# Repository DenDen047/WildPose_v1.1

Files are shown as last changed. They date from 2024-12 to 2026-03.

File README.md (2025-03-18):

<p align="center">
  <h1 align="center">WildPose v1.1</h1>
  <p align="center">
    <a href="https://denden047.github.io/index_en.html">Naoya Muramatsu</a>
    ·
    <a href="https://www.linkedin.com/in/sangyun-shin-profile/?originalSubdomain=uk">Sangyun Shin</a>
    ·
    <a href="https://uk.linkedin.com/in/qianyi-deng">Qianyi Deng</a>
    ·
    <a href="https://www.cs.ox.ac.uk/people/andrew.markham/">Andrew Markham</a>
    ·
    <a href="https://scholar.google.com/citations?user=RxMigV4AAAAJ&hl=en">Amir Patel</a>
  </p>
  <h4 align="center">
    📚 <a href="https://www.biorxiv.org/content/10.1101/2024.02.05.578861v3">Paper</a> |
    🦒 <a href="https://denden047.github.io/wildpose">Project Page</a> |
    📂 <a href="https://u.pcloud.link/publink/show?code=kZdoxE0Z9rRj956ptaH6h0Btymik4X0jtGm7">Data</a>
  </h3>
</p>

<p align="center">

</p>
<div align=center>
This is the official implementation of our paper <a href="https://www.biorxiv.org/content/10.1101/2024.02.05.578861v4"><b>WildPose: A Long-Range 3D Wildlife Motion Capture System</b></a>.
</div>

## Citation

```bibtex
@article{10.1242/jeb.249987,
    author = {Muramatsu, Naoya and Shin, Sangyun and Deng, Qianyi and Markham, Andrew and Patel, Amir},
    title = {WildPose: a long-range 3D wildlife motion capture system},
    journal = {Journal of Experimental Biology},
    volume = {228},
    number = {5},
    pages = {JEB249987},
    year = {2025},
    month = {03},
    issn = {0022-0949},
    doi = {10.1242/jeb.249987},
    url = {https://doi.org/10.1242/jeb.249987},
    eprint = {https://journals.biologists.com/jeb/article-pdf/228/5/JEB249987/3637925/jeb249987.pdf},
}
```

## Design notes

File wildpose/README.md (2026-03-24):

# WildPose v1.1

## Hardware

### XIMEA -- MQ022CG-CM

Slide86

## Prerequisite

- JetPack v5
- ROS2 Foxy

## Setup

### Jetson AGX Xavier Developer Kit

#### JetPack

We used a [Jetson AGX Xavier Developer Kit](https://developer.nvidia.com/embedded/jetson-agx-xavier-developer-kit).
To set up the Jetson AGX Xavier Developer Kit, we need a host computer installed Ubuntu 20.04.

1. Download and install [NVIDIA SDK Manager](https://developer.nvidia.com/nvidia-sdk-manager) onto the host computer.
2. Connect the host computer and Jetson AGX Xavier Developer Kit (see this [video](https://www.youtube.com/watch?v=-nX8eD7FusQ)).
3. Run NVIDIA SDK Manager and follow the instruction.

Unleash the limitation of CPU ([the reference](https://forums.developer.nvidia.com/t/cpus-usage-problem-solved/65993/3)).
```bash
$ sudo nvpmodel -m 0
$ sudo /usr/bin/jetson_clocks --fan
```

#### General Settings

- Settings > Power > Blank Screen > `Never`

#### Network Configuration

On the Jetson, you can use `nmcli` command to change the network settings.

Set the static IP on the UCT network ([reference](https://f1tenth.readthedocs.io/en/stable/getting_started/software_setup/optional_software_nx.html)).
```bash
$ nmcli c show
NAME                UUID                                  TYPE      DEVICE
Wired connection 1  b72f3d20-4de2-3d44-9c45-9689d79f22e4  ethernet  eth0
docker0             bcb6f95d-5cf5-483d-ac09-c312a4da8c0b  bridge    docker0
$ sudo nmcli c modify "Wired connection 1" ipv4.address [NEW_ADDRESS]/27
```

#### SSH

***HOST COMPUTER***

For the ssh login from your computer, you should make a pair of ssh key on the host computer.
```bash
$ ssh-keygen -t rsa
```

Then, copy the public key into the Jetson.
```bash
$ ssh-copy-id -i ~/.ssh/wildpose_jetsonagx.pub [user]@[ip address]
```

Add the jetson IP address information in `~/.ssh/config`:
```
Host [ip address]
    HostName [ip address]
    User naoya
    IdentityFile ~/.ssh/wildpose_jetsonagx
    UseKeychain yes
    AddKeysToAgent yes
```

#### dotfiles

Set the dotfiles you wanna use (e.g., [Naoya's dotfiles](https://github.com/DenDen047/dotfiles)).

#### ROS2 Foxy

Let's install [ROS2 Foxy](https://docs.ros.org/en/foxy/index.html) following with [the official guide](https://docs.ros.org/en/foxy/Installation/Ubuntu-Install-Debians.html).
See `setup_scripts/ros2_foxy.sh`.

```bash
$ cd setup_scripts
$ ./ros2_foxy.sh
```

#### The Official Ximea Camera Driver

This is [the original GitHub repository](https://github.com/wavelab/ximea_ros_cam) and [the Guide for Jetson](https://www.ximea.com/support/wiki/apis/Linux_TX1_and_TX2_Support#Installing-XIMEA-API-package).

```bash
$ cd setup_scripts/
$ chmod +x ./xiapi.sh
$ ./xiapi.sh
# reopen the shell
```

##### Setup the USB FS Memory Max Allocation to Infinite

This is done to make sure that the USB FS buffering size is sufficient for high bandwidth streams through USB 3.0

*Set this with every new shell*:
Put `echo 0 > /sys/module/usbcore/parameters/usbfs_memory_mb` into `/etc/rc.local`

Or

*Apply to current shell*:
`echo "0" | sudo tee /sys/module/usbcore/parameters/usbfs_memory_mb`

#### ROS2 Packages

To show the ximea camera image data, you are recommended to install [image_view](https://index.ros.org/p/image_view/).

```bash
$ sudo apt install -y ros-foxy-image-view \
    ros-foxy-rqt-image-view \
    ros-foxy-rqt-reconfigure \
    ros-foxy-image-transport-plugins \
    ros-foxy-camera-info-manager
```

#### XIMEA Camera Driver for ROS2

```bash
$ mkdir ~/ros2_ws
$ cd ~/ros2_ws
$ git clone git@github.com:African-Robotics-Unit/ximea_ros2_cam.git
$ cd ~/ros2_ws/ximea_ros2_cam/
$ git fetch
$ git checkout -b develop
$ sudo apt install -y ros-foxy-camera-info-manager
$ colcon build
$ colcon build --packages-select cam_bringup --symlink-install

# Test the camera driver
$ ros2 launch cam_bringup cam_test.launch.py
```

Then, add `source ~/ros2_ws/ximea_ros2_cam/install/setup.bash` into `~/.bashrc`.

To avoid the [error 45](https://github.com/Fu-physics/Ximea/blob/master/xiPython/v3/ximea/xidefs.py#L49), you have to run the following command.

```bash
$ sudo tee /sys/module/usbcore/parameters/usbfs_memory_mb >/dev/null <<<0
```

#### Livox-SDK

This is [the original GitHub repository](https://github.com/Livox-SDK/Livox-SDK).

```bash
$ sudo apt install -y cmake gcc-aarch64-linux-gnu g++-aarch64-linux-gnu
$ cd ~/Documents
$ git clone https://github.com/Livox-SDK/Livox-SDK.git
$ cd Livox-SDK
```

Edit `Livox-SDK/sdk_core/CMakeLists.txt` by adding `-fPIC`.
Ref: https://github.com/Livox-SDK/livox_ros2_driver/issues/9#issuecomment-1048578018

```bash
$ cd build && cmake .. -DCMAKE_SYSTEM_NAME=Linux -DCMAKE_C_COMPILER=aarch64-linux-gnu-gcc -DCMAKE_CXX_COMPILER=aarch64-linux-gnu-g++
$ make
$ sudo make install
$ source /opt/ros/foxy/setup.bash
```

Set the network configuration:
- IP address: `192.168.1.2`
- Netmask: `255.255.255.0`
- Gatway: `192.168.1.1`

#### Livox ROS2 Driver

This is [the original GitHub repository](https://github.com/Livox-SDK/livox_ros2_driver).

```bash
$ sudo apt install -y ros-foxy-rviz2
$ cd ~/ros2_ws
$ git clone https://github.com/DenDen047/livox_ros2_driver.git livox_ros2_driver/src
$ cd livox_ros2_driver
$ colcon build
$ source ~/ros2_ws/livox_ros2_driver/install/setup.bash
```

Add `source ~/ros2_ws/livox_ros2_driver/install/setup.bash` into `~/.bashrc`.
Don't forget to change **the config file**.

#### rmw_ecal

Update the ROS middleware for fast recording ros bag files.

Install [eCAL](https://github.com/eclipse-ecal/ecal).
```bash
$ sudo add-apt-repository ppa:ecal/ecal-latest
$ sudo apt-get update
$ sudo apt-get install -y ecal
```

Setup [rosidl_typesupport_protobuf](https://github.com/eclipse-ecal/rosidl_typesupport_protobuf).
```bash
$ sudo apt-get install -y libprotobuf-dev protobuf-compiler
$ cd ~/ros2_ws
$ git clone https://github.com/eclipse-ecal/rosidl_typesupport_protobuf.git
$ cd ~/ros2_ws/rosidl_typesupport_protobuf
$ colcon build
$ vim ~/.bashrc   # add "source ~/ros2_ws/rosidl_typesupport_protobuf/install/setup.bash"
$ source ~/.bashrc
```

Clone latest release of this repository into your ROS2 workspace and build it.
```bash
$ cd ~/ros2_ws
$ git clone https://github.com/eclipse-ecal/rmw_ecal.git
$ cd ~/ros2_ws/rmw_ecal
$ colcon build --packages-skip rmw_ecal_proto_cpp
$ vim ~/.bashrc   # add "source ~/ros2_ws/rmw_ecal/install/setup.bash"
$ source ~/.bashrc
```

Add the following line into your `.bashrc`.
```bash
export RMW_IMPLEMENTATION=rmw_ecal_dynamic_cpp
```

Install Python eCAL API.
```bash
$ sudo apt install -y python3 python3-pip
$ sudo apt install -y python3-ecal5
```

#### jtop

To check the Jetson status, [`jtop`](https://github.com/rbonghi/jetson_stats) should be installed.
```bash
$ sudo -H pip install -U jetson-stats
$ sudo reboot
```

#### Wi-Fi

You should get a connection listing similar to something like this:

```bash
$ nmcli d
DEVICE         TYPE      STATE         CONNECTION
wlan0          wifi      connected     AirPort41594
docker0        bridge    connected     docker0
p2p-dev-wlan0  wifi-p2p  disconnected  --
eth0           ethernet  unavailable   --
...
```

Next we will make sure that the WiFi module is turned on by typing the following command:

```bash
$ nmcli r wifi on
```

Now we can scan and list off all visible WiFi networks available to us by typing the following command:

```bash
$ nmcli d wifi list
IN-USE  BSSID              SSID          MODE   CHAN  RATE        SIGNAL  BARS  SECURITY
*       34:76:C5:37:A2:7A  AirPort41594  Infra  6     130 Mbit/s  87      ▂▄▆█  WPA1 WPA2
...
```

To connect to a given network make sure you have its SSID and password ready. Both are case sensitive! Type the following command with `[SSID]` being your SSID and `[PASSWORD]` being the password for that network:

```bash
$ nmcli d wifi connect [SSID] password [PASSWORD]
```

If all goes according to plan, you should get a connection confirmation!

#### CAN bus setting

```bash
$ sudo apt install -y busybox
```

Add the following code into your `/etc/rc.local`:
```bash
sh /home/naoya/WildPose_v1.1/wildpose/src/dji_rs3_pkg/enable_CAN.sh &
```

Check the status of `can0`:
```bash
$ ip -s -d -h link show can0
```

Check the CAN connection.
```bash
# AA:1A:00:03:00:00:00:00  22:11:A2:42:0E:00:20:00  30 00 40 00 01 14 7B 40  97 BE
$ cansend can0 223#AA1A000300000000 && \
    cansend can0 223#2211A2420E002000 && \
    cansend can0 223#3000400001147B40 && \
    cansend can0 223#97BE
```

References:
- [Enabling CAN on Nvidia Jetson Xavier Developer Kit](https://medium.com/@ramin.nabati/enabling-can-on-nvidia-jetson-xavier-developer-kit-aaaa3c4d99c9)
- [hmxf/can_xavier -- GitHub](https://github.com/hmxf/can_xavier)
- [Controller Area Network (CAN) -- nVIDIA](https://docs.nvidia.com/jetson/archives/r34.1/DeveloperGuide/text/HR/ControllerAreaNetworkCan.html)

#### Remote Desktop

```bash
$ sudo apt install -y xrdp
$ cd
$ echo "xfce4-session" | tee .xsession
$ sudo reboot
```

#### Logitech Wireless Gamepad F710

Mode `X`.

```bash
$ usb-devices
...
T:  Bus=01 Lev=02 Prnt=03 Port=02 Cnt=01 Dev#= 10 Spd=12  MxCh= 0
D:  Ver= 2.00 Cls=ff(vend.) Sub=ff Prot=ff MxPS= 8 #Cfgs=  1
P:  Vendor=046d ProdID=c21f Rev=03.05
S:  Manufacturer=Logitech
S:  Product=Wireless Gamepad F710
S:  SerialNumber=3DA39E79
C:  #Ifs= 1 Cfg#= 1 Atr=80 MxPwr=98mA
I:  If#=0x0 Alt= 0 #EPs= 2 Cls=ff(vend.) Sub=5d Prot=01 Driver=xpad
...
```

Check the connection between Jetson and F710.

```bash
$ sudo apt-get install -y jstest-gtk
$ jstest /dev/input/js0
```

Install `joy_linux` package.

```bash
$ sudo apt install -y ros-foxy-joy-linux
$ ros2 run joy_linux joy_linux_node --ros-args -p dev_name:="Wireless Gamepad F710"
```

#### Motor Controller with Teensy 4.0

Install the preprequirements.

```bash
$ sudo apt-get install -y python3-serial
```

TTY setting.

```bash
$ systemctl stop nvgetty
$ systemctl disable nvgetty
$ udevadm trigger
```

Add an user group, `dialout`, to use tty ports without sudo.

```bash
$ sudo usermod -aG dialout ${USER}
```

Then, you should reboot the jetson.

References
- [Jetson Nano – UART](https://jetsonhacks.com/2019/10/10/jetson-nano-uart/)
- [Permission denied when try connect on /dev/ttyTHS1](https://forums.developer.nvidia.com/t/permission-denied-when-try-connect-on-dev-ttyths1/210479/10)

#### Jetson AGX Orin for Teensy 4.0

This is the setup on Jetson AGX Orin for Teensy 4.0.

```bash
$ sudo usermod -a -G tty naoya
```

### Host Computer

To develop ROS2 programs on your host/local computer, VS Code ROS Extension was used.
Please refer to see the following video:

<iframe width="560" height="315" src="https://www.youtube.com/embed/teA20AjBlG8" title="YouTube video player" frameborder="0" allow="accelerometer; autoplay; clipboard-write; encrypted-media; gyroscope; picture-in-picture" allowfullscreen></iframe>

#### VSCode

Recommend Extensions:
- [C/C++ Extension Pack](https://marketplace.visualstudio.com/items?itemName=ms-vscode.cpptools-extension-pack)
- [CMake](https://marketplace.visualstudio.com/items?itemName=twxs.cmake)
- [Python](https://marketplace.visualstudio.com/items?itemName=ms-python.python)
- [ROS2](https://marketplace.visualstudio.com/items?itemName=nonanonno.vscode-ros2)

## Build

```bash
$ cd ~/WildPose_v1.1/wildpose
$ colcon build --symlink-install
```

## Usage

Run WildPose with the following commmand, and the data will be recorded in a rosbag file in `rosbags/`.

```bash
$ sudo ip link set down can0 && sudo ip link set up can0
$ ros2 launch wildpose_bringup wildpose_launch.py
```

After that, you can open eCAL Recorder.
Note that `cam_context` file is generated when the system starts up, so its timestamp will always be earlier than that of the eCAL file.

```bash
$ ecal_rec_gui --config ~/WildPose_v1.1/wildpose/src/wildpose_bringup/config/config.ecalrec --activate
```

## Generate Video

Install requirements:

```bash
$ sudo apt install -y ffmpeg
$ sudo apt install -y python3-roslib python3-rospy python3-sensor-msgs python3-opencv
$ pip3 install tqdm ffmpeg-python
```

Convert a rosbag file into a video file:

```bash
$ cd src/
$ ./rosbag2video.py --input_db ~/WildPose_v1.1/wildpose/rosbags/20221002_192302/20221002_192302_0.db3
```

## Replay

```bash
$ ros2 run image_view image_view --ros-args --remap /image:=/image_raw
```

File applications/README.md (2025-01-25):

# WildPose Applications

This repository contains the code for the figures and tables in the WildPose paper.

## Setting up the environment

```bash
conda env create -f environment.yml
conda activate wildpose
```

## File Organization for a scene data

The data is organized as follows:

```
data/
├── manual_calibration.json
├── sync_rgb/
│   ├── 000001.jpeg
│   ├── 000002.jpeg
│   ├── 000003.jpeg
│   ├── ...
├── lidar/
│   ├── 000001.pcd
│   ├── 000002.pcd
│   ├── 000003.pcd
│   ├── ...
├── masks/
    ├── 000001.png
    ├── 000002.png
    ├── 000003.png
    ├── ...
```

where `sync_rgb` is the synchronized RGB images, `lidar` is the LiDAR point clouds, and `masks` is the masks of the animals.

## Making the figures and tables in the WildPose paper

### Introduction section

Fig. 1D.
```bash
python make_depth_image.py
```

### Calibration Validation

For the calibration validation figures (Fig. 2A), run:
```bash
python plot_calib_validation.py             # Fig. S1
python plot_calib_validation_by_angles.py   # Fig. 2A
```

### Object Tracking Precision

Analyze the validation results of the object tracking precision.
```bash
# First, run the validation:
python validate_trajectory.py \
    --mode position_2d \
    --data_dir /path/to/data
./batch_validate_trajectory.sh

# Then generate figures:
python plot_trajectory_validation_by_circles.py # Fig. 2D
python plot_motion_validation.py                # Fig. 2E
python create_synthetic_figure.py               # Fig. S2
```

### Animal Morphology & Locomotion

Get the morphometrics data (Table 1).
```bash
python measure_morphometrics.py
```

Fig. 3A&B.
```bash
python plot_keypoints.py
```

- `single_frame` mode (Fig. 3A)
- `left_{front|hind}_leg` mode (Fig. 3B)

Fig. S3.
```bash
python plot_coloured_pcd.py
```

### Tracking Individual Animals in 3D

```bash
python plot_3d_trajectory.py    # Supports multiple modes:
# --mode position_3d            # Fig. S4A
# --mode position_without_y     # Fig. 3C
# --mode velocity               # Fig. S4B-D
# --mode neighbor_density       # Fig. 3D
# --mode neighbor_density_animation # Movie 1
```

### Fine Scale Deformation Monitoring

Prerequisites:
1. Generate bounding boxes for target animals
2. Predict individual masks using Segment Anything (`segment_anything.py`)
3. Estimate body size transitions (`body_size_estimator.py`)

```bash
python plot_breathing.py    # Supports modes:
# --mode filtered   # Fig. 4A
# --mode fft        # Fig. 4B
# --mode imu        # Fig. 4C and 4D
```

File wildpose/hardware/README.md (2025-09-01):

# Wildpose_CAD_Model
This is the CAD Folder including all the files for the Wildpose Camera Rig.

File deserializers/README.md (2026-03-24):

logo

# eCAL Deserializers

## Description

This repo contains deserializers for [eCAL](https://github.com/eclipse-ecal/rmw_ecal) measurements of four ROS2 messages used in our [M2S2](m2s2_ws) drivers.

The deserializers extract the raw data stored in the .hdf5 files and converts it into desirable data according to their message definitons.

Messages:

1. standard [ROS2](https://docs.ros.org/en/foxy/index.html) sensor_msgs/msg/Image
2. custom M2S2 flir_boson_interfaces/msg/ThermalRaw
3. custom M2S2 bme280_interfaces/msg/EnviroData
4. custom M2S2 radar_interfaces/msg/Frame

## Install

[eCAL](https://github.com/eclipse-ecal/ecal)

```bash
sudo add-apt-repository ppa:ecal/ecal-5.13
sudo apt update
sudo apt install -y ecal
```

[ROS2 Humble](https://docs.ros.org/en/humble/Installation/Ubuntu-Install-Debs.html)

```bash
sudo apt install software-properties-common
sudo add-apt-repository universe

sudo apt update && sudo apt install curl -y
export ROS_APT_SOURCE_VERSION=$(curl -s https://api.github.com/repos/ros-infrastructure/ros-apt-source/releases/latest | grep -F "tag_name" | awk -F\" '{print $4}')
curl -L -o /tmp/ros2-apt-source.deb "https://github.com/ros-infrastructure/ros-apt-source/releases/download/${ROS_APT_SOURCE_VERSION}/ros2-apt-source_${ROS_APT_SOURCE_VERSION}.$(. /etc/os-release && echo ${UBUNTU_CODENAME:-${VERSION_CODENAME}})_all.deb"
sudo dpkg -i /tmp/ros2-apt-source.deb

sudo apt update && sudo apt upgrade -y
sudo apt install -y ros-humble-desktop ros-dev-tools
mkdir -p ~/ros2_ws/src

# add the below command to .bashrc
source /opt/ros/humble/setup.bash

rosdep init
rosdep update
```

[rmw_ecal](https://github.com/eclipse-ecal/rmw_ecal)

```bash
cd ~/ros2_ws/src
sudo apt install -y \
    ros-humble-osrf-testing-tools-cpp \
    ros-humble-test-msgs \
    ros-humble-image-view
git clone https://github.com/eclipse-ecal/rosidl_typesupport_protobuf.git
git clone https://github.com/eclipse-ecal/rmw_ecal
sudo apt install -y libprotobuf-dev protobuf-compiler
colcon build --symlink-install --cmake-args -DBUILD_TESTING=OFF

# add the below commands to ~/.bashrc
export RMW_IMPLEMENTATION=rmw_ecal_dynamic_cpp
source ~/ros2_ws/src/install/setup.bash
```

## Trim eCAL measurement file

Usually, eCAL data is super large.
So, we recommend to [trim the eCAL file](https://eclipse-ecal.github.io/ecal/stable/applications/meas_cutter/meas_cutter.html) before deserialisation.

First, you need to check the timestamp on eCAL player and ROS2 `image_view`:

```bash
ros2 run image_view image_view --ros-args --remap /image:=/image_raw
```

Then edit the `deserializers/ecal_cutter_config.yml` and run eCAL cutter:

```bash
cd deserializers
vim ecal_cutter_config.yml
./ecal_cutter.sh
```

Or you can cut scenes at once:

```bash
cd deserializers
uv run python batch_ecal_cutter.py
```

Note: the input and output arguments of `ecal_meas_cutter` should be folder paths.

## Usage

First of all, you have build the whole folder.

```bash
$ cmake .
```

Or run at once:

```bash
$ cd deserializers
$ sudo apt update && sudo apt install -y ffmpeg
$ uv run python deserializer.py --meas_dir [meas_dir_path] --skip_raw
```

Or you can batch-deserialize:

```bash
$ cd deserializers
$ LOGURU_LEVEL=INFO uv run python batch_deserializer.py --parent_dir [parent_dir_of_meas_dirs]
```

## YouTube Batch Upload

Upload videos to YouTube with pCloud shared links in the description.

### Upload new videos

```bash
uv run python batch_uploader.py --parent_dir /mnt/vault/WildPose_dataset
```

### Dry run (preview without uploading)

```bash
uv run python batch_uploader.py --parent_dir /mnt/vault/WildPose_dataset --dry_run
```

### Update descriptions of already-uploaded videos

Add pCloud shared links to existing YouTube videos:

```bash
uv run python batch_uploader.py --parent_dir /mnt/vault/WildPose_dataset --update_descriptions
```

Preview changes first:

```bash
uv run python batch_uploader.py --parent_dir /mnt/vault/WildPose_dataset --update_descriptions --dry_run
```

### Prerequisites

- YouTube OAuth2 token (see setup below)
- [rclone](https://rclone.org/) configured with `pCloud:` remote (for pCloud shared links)

### YouTube OAuth2 token setup

1. Create a project on [Google Cloud Console](https://console.cloud.google.com/) and enable YouTube Data API v3
2. Go to "APIs & Services > Credentials" and create an OAuth 2.0 Client ID (type: Desktop app)
3. Download the client secret JSON and place it at:
   ```
   .secrets/youtube_api_v3_client_secret.json
   ```
4. Run the authentication script (a browser window will open for Google account login):
   ```bash
   uv run python tools/test_youtube_auth.py
   ```
5. On success, the token is saved to `.secrets/youtube_token.json`

**Token renewal**: If you get an `invalid_grant` error, delete the token file and re-authenticate:

```bash
rm .secrets/youtube_token.json
uv run python tools/test_youtube_auth.py
```

### Ximea Camera Deserializer

This [deserializer](src/deserialize_ximea.cpp) converts a recorded ecal measurement of type [sensor_msgs/msg/Image](http://docs.ros.org/en/noetic/api/sensor_msgs/html/msg/Image.html) into RGB .jpeg images.

**NOTE:** Ximea API's demosaic color defect correction is not optimized for ARM processors, and so performance may degrade significantly. To avoid this, we captured raw 8-bits or 16-bits images (by setting the *format* parameter to **RAW8** or **RAW16** in the config file of the [M2S2 ROS2 driver](add link)) and we post-process later using the API's [offline processing](https://www.ximea.com/support/wiki/apis/XiAPI_Offline_Processing), by saving the camera context each time data is collected.

[xiAPI](https://www.ximea.com/support/wiki/apis/XIMEA_Linux_Software_Package)

```bash
# download package
wget  https://updates.ximea.com/public/ximea_linux_sp_beta.tgz
tar xzf ximea_linux_sp_beta.tgz
cd package

# install
sudo apt-get update
sudo apt-get install build-essential linux-headers-"$(uname -r)"
sudo apt-get install libtiff5
./install
```

build with:

```bash
$ cmake --build . --target ximea
```

run:

```bash
./ecal_sample_ximea 'meas_folder_path' 'channel_name' 'cam_context_path' 'out_path_rgb' 'out_path_raw' [image_format]
```

where:

- `meas_folder_path` is the path to the input eCAL measurement folder
- `channel_name` is the channel you wish to deserialize. (This is often `rt/image_raw`)
- `cam_context_path` is the path to where the camera context file is saved for a specific measurement, to perform post-processing of the raw ximea images
- `out_path_rgb` is the path to where you wish to store the post-processed RGB images
- `out_path_raw` is the path to where you wish to store the post-processed RAW images (set to `none` to skip raw image generation)
- `image_format` (optional) is the output image format for RGB images: `webp` (default, lossless) or `jpeg` (quality=95)

Examples:

```bash
# Generate both RGB and RAW images (default: WebP format)
./ecal_sample_ximea /path/to/meas rt/image_raw /path/to/cam_context.bin /path/to/rgb/ /path/to/raw/

# Generate only RGB images (skip RAW)
./ecal_sample_ximea /path/to/meas rt/image_raw /path/to/cam_context.bin /path/to/rgb/ none

# Generate RGB images in JPEG format (skip RAW)
./ecal_sample_ximea /path/to/meas rt/image_raw /path/to/cam_context.bin /path/to/rgb/ none jpeg
```

### Livox Deserializer

This [deserializer](src/deserialize_livox.cpp) converts a recorded ecal measurement of type [sensor_msgs/msg/PointCloud2](http://docs.ros.org/en/melodic/api/sensor_msgs/html/msg/PointCloud2.html) into a pcd file using the [Point Cloud Library](https://github.com/PointCloudLibrary/pcl).

dependencies:

```bash
$ sudo apt install -y libpcl-dev
$ sudo apt install -y python3-pcl pcl-tools
$ git clone git@github.com:PointCloudLibrary/pcl.git
$ cd pcl
$ mkdir build
$ cd build
$ cmake ..
$ make -j8
$ sudo make install
```

build with:

```bash
$ cmake --build . --target livox_imu lidar
```

run:

```bash
$ ./ecal_sample_lidar 'meas_folder_path' 'channel_name' 'out_path'
```

where:

- `meas_folder_path` is the path to the input eCAL measurement folder
- `channel_name` is the channel you wish to deserialize. (This is often `rt/livox/lidar`)
- `out_path` is the folder path to where you wish to store the pcd files

The IMU data structure:

```msg
std_msgs/Header header
    int32 sec
    int32 nanosec
    string frame_id

geometry_msgs/Quaternion orientation
    float64 x   # Default: 0
    float64 y   # Default: 0
    float64 z   # Default: 0
    float64 w   # Default: 1
float64[9] orientation_covariance   # Row major about x, y, z axes

geometry_msgs/Vector3 angular_velocity
    float64 x
    float64 y
    float64 z
float64[9] angular_velocity_covariance  # Row major about x, y, z axes

geometry_msgs/Vector3 linear_acceleration
    float64 x
    float64 y
    float64 z
float64[9] linear_acceleration_covariance   # Row major x, y z
```

### BME280 Deserializer

This [deserializer](src/deserialize_bme280.cpp) converts a recorded ecal measurement of type [bme280_interfaces/msg/EnviroData](m2s2_ws/src/bme280_ROS2_driver/bme280_interfaces/msg/EnviroData.msg) into a JSON file with the following fields for each measurement: frame_id, timestamp_secs, timestamp_nanosecs, temperature, pressure, humidity.

build with:

```bash
$ cmake --build . --target bme280
```

run:

```bash
./ecal_sample_bme280 'meas_path' 'channel_name' 'out_file_name'
```

where:

- `meas_path` is the path to the input eCAL measurement file
- `channel_name` is the channel you wish to deserialize. (This is often `rt/ros2_topic_name`)
- `out_file_name` is the name of the JSON file you wish to save the data to

### FLIR Boson Deserializer

This [deserializer](src/deserialize_flir_boson.cpp) converts a recorded ecal measurement of type [flir_boson_interfaces/msg/ThermalRaw](m2s2_ws/src/flir_boson_ROS2_driver/flir_boson_interfaces/msg/ThermalRaw.msg) into raw 16 bit .png images, as well as grayscale false-coloured .jpeg images.

build with:

```bash
$ cmake --build . --target boson
```

run:

```bash
./ecal_sample_boson 'meas_path' 'channel_name' 'out_path_raw' 'out_path_rgb'
```

where:

- `meas_path` is the path to the input eCAL measurement file
- `channel_name` is the channel you wish to deserialize. (This is often `rt/ros2_topic_name`)
- `out_path_raw` is the path to where you wish to store the 16 bit raw images
- `out_path_rgb` is the path to where you wish to store the false-coloured images

### Radar Deserializer

This [deserializer](src/deserialize_radar.cpp) converts a recorded ecal measurement of type [radar_interfaces/msg/Frame](m2s2_ws/src/radar_ROS2_driver/radar_interfaces/msg/Frame.msg) into a JSON file with the following fields for each radar frame: frame_id, timestamp_secs, timestamp_nanosecs, frame_size, frame_data.

build with:

```bash
$ cmake --build . --target radar
```

run:

```bash
./ecal_sample_radar 'meas_path' 'channel_name' 'out_file_name'
```

where:

- `meas_path` is the path to the input eCAL measurement file
- `channel_name` is the channel you wish to deserialize. (This is often `rt/ros2_topic_name`)
- `out_file_name` is the name of the JSON file you wish to save the data to

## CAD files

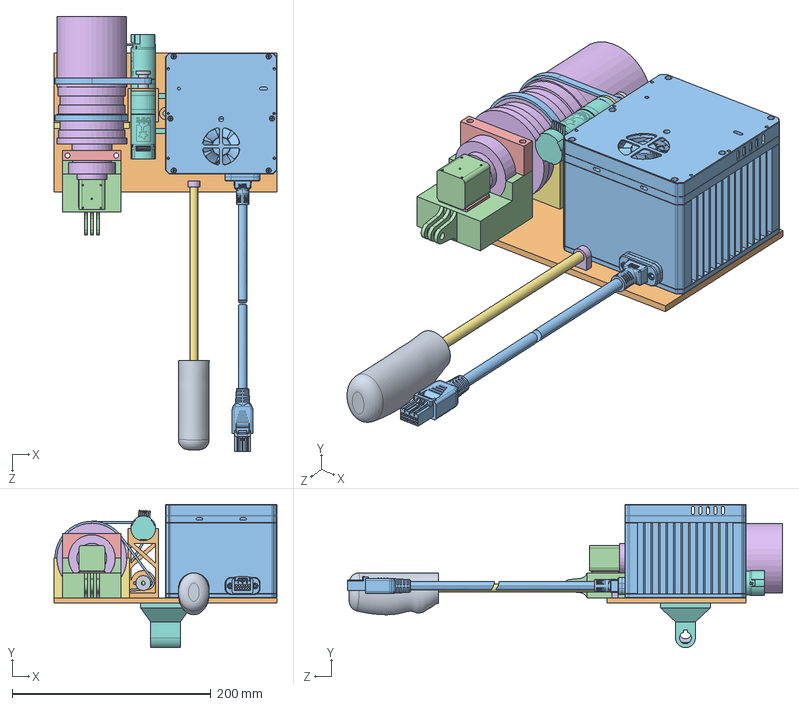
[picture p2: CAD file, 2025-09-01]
wildpose/hardware/CameraAssembly.SLDASM
224.0 x 144.2 x 437.2 mm
WLDPOSE009 Camera Plate
Tele-15_shell_FOV_3D.stp
Zimea Camera MQ022CG-CM
Camera Mount
Lens
Lens Support
25d-metal-gearmotor-75-99-encoder.step x 2
Belt Pulley 778-4828 x 2
Motor Mount
Motor Belt x 2
Ximea Holder
Ximea Holder 2
WLDPOSE010 Handle Connector
HandleRod
WLDPOSE008 Pitch Shaft Connector v2
Handle

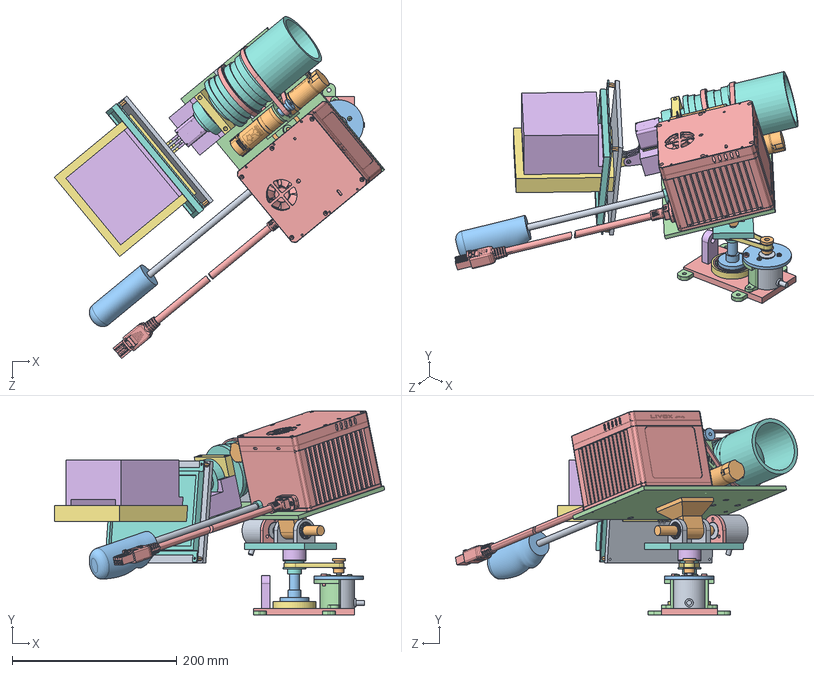
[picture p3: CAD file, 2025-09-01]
wildpose/hardware/Full Rig.SLDASM
401.7 x 247.6 x 415.7 mm
Optical Encoder x 2
18 T 2.032mm P , 6mm W Pulley
Encoder Coupler
DIN 7984 - M3 x 10 --- 8.5NPCS x 3
DIN 6912 - M4 x 12 --- 8.5NPCS x 2
Nvidea Xavier
Xavier Holder
QLED Screen
Screen Mount
RPi M3 Screw Connectors x 4
WLDPOSE009 Camera Plate
Tele-15_shell_FOV_3D.stp
Zimea Camera MQ022CG-CM
Camera Mount
Lens
Lens Support
25d-metal-gearmotor-75-99-encoder.step x 2
Belt Pulley 778-4828 x 2
Motor Mount
Motor Belt x 2
Ximea Holder
Ximea Holder 2
WLDPOSE010 Handle Connector
HandleRod
WLDPOSE008 Pitch Shaft Connector v2
Handle
WLDPOSE001 Base Wing Slots x 4
WLDPOSE002 Base Bilot
WLDPOSE003 Base Shaft Support Slot
WLDPOSE004 Bearing Holder
WLDPOSE005 Pitch Bilot
WLDPOSE006 Shaft Holder x 2
WLDPOSE007 Pitch Shaft
WLDPOSE011 Yaw shaft
Base Encoder Holder (Printed)
Pitch Encoder Holder (Printed)
Shaft Spacer (Printed)
Timing Belt 80 T 162.56mm x 6mm
36 T 2.032mm P, 6mm W Pulley
SKF_61801_16 x 24
SKF_61801_29 x 2
SKF_61801_31 x 2
SKF_61807_23 x 19
SKF_61807_43
SKF_61807_45
SKF_51200_3 x 9
SKF_51200_13
SKF_51200_15
SKF_51200_17

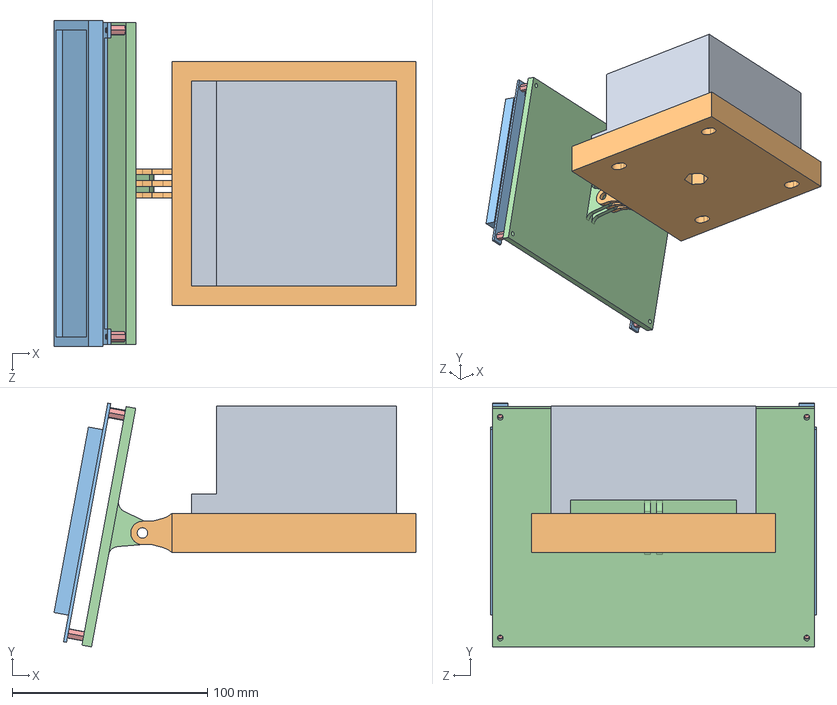
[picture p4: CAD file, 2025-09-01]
wildpose/hardware/Nvidea_Screen_Setup.SLDASM
185.3 x 124.8 x 166.9 mm
Nvidea Xavier
Xavier Holder
QLED Screen
Screen Mount
RPi M3 Screw Connectors x 4

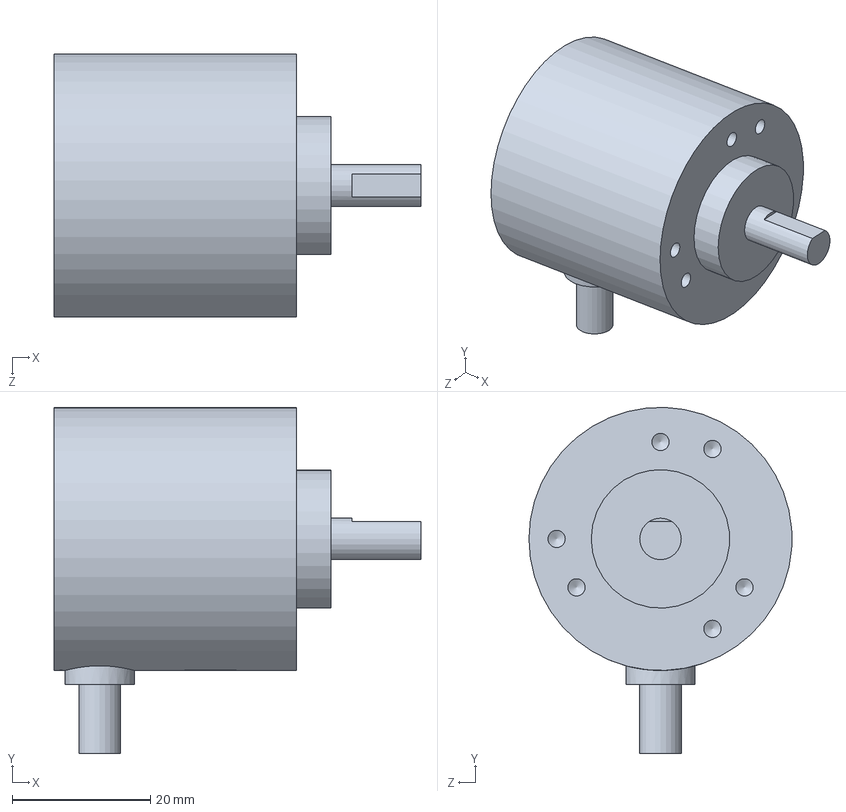
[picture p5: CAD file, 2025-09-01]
wildpose/hardware/Optical Encoder.SLDPRT
53.0 x 50.0 x 38.0 mm

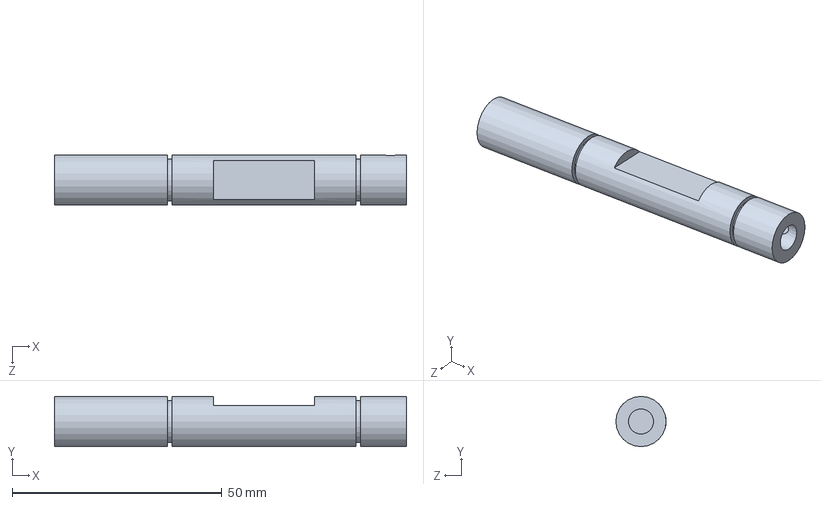
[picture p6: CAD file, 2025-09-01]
wildpose/hardware/WLDPOSE007 Pitch Shaft.SLDPRT
84.0 x 12.0 x 12.0 mm

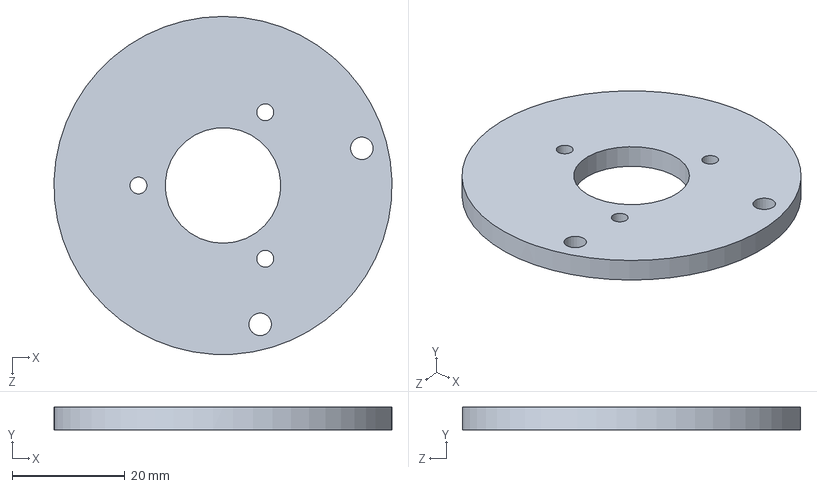
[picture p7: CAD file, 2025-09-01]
wildpose/hardware/Encoder Coupler.SLDPRT
60.0 x 4.00 x 60.0 mm

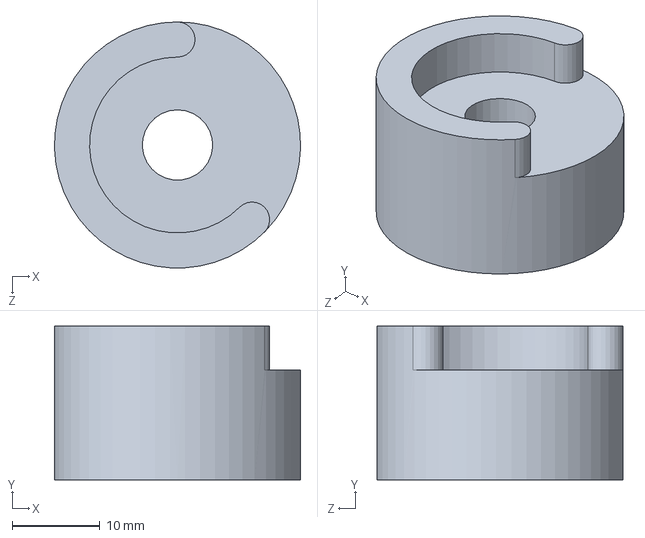
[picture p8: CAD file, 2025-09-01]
wildpose/hardware/Shaft Spacer (Printed).SLDPRT
28.0 x 17.5 x 28.0 mm

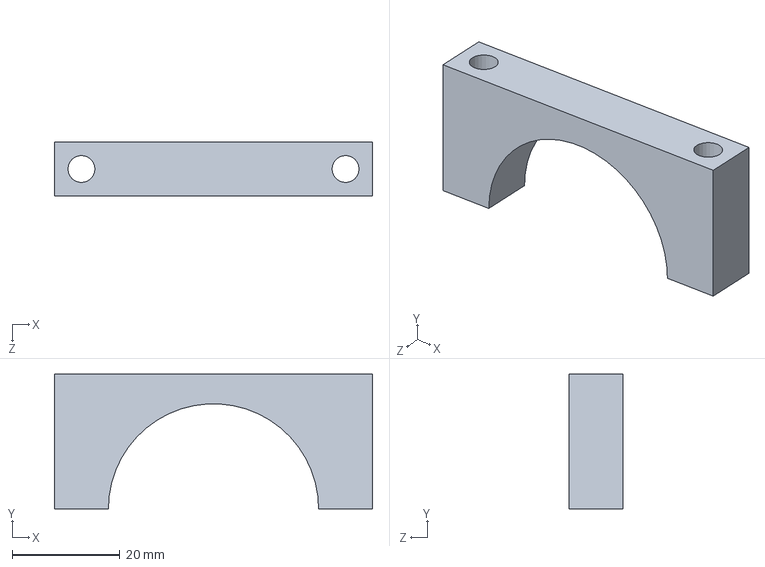
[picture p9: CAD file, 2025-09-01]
wildpose/hardware/Ximea Holder 2.SLDPRT
59.0 x 25.0 x 10.0 mm

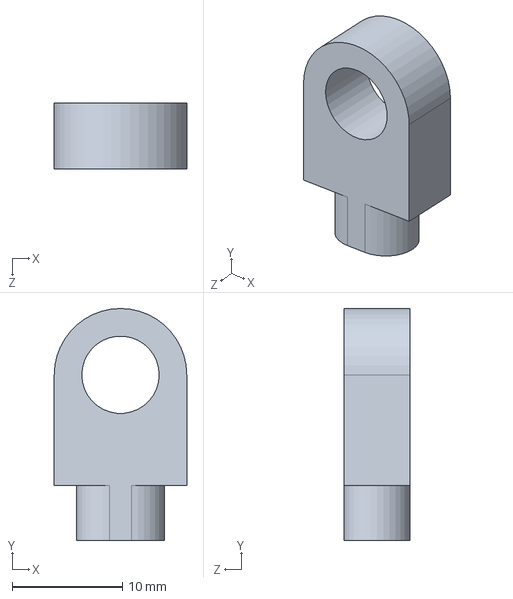
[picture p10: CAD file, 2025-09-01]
wildpose/hardware/WLDPOSE010 Handle Connector.SLDPRT
12.0 x 21.0 x 6.00 mm

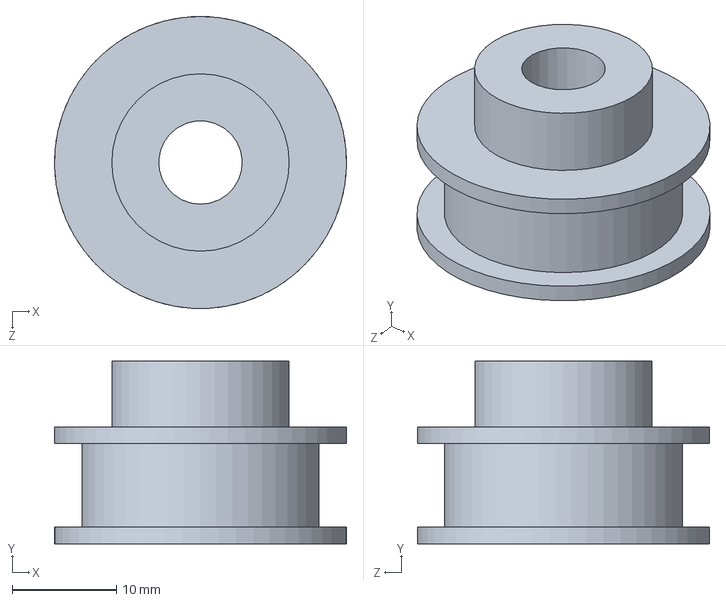
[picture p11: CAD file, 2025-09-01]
wildpose/hardware/36 T 2.032mm P, 6mm W Pulley.SLDPRT
28.0 x 17.5 x 28.0 mm

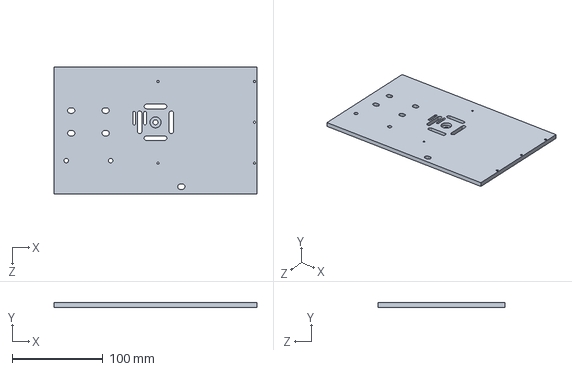
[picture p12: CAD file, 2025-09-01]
wildpose/hardware/WLDPOSE009 Camera Plate.SLDPRT
224.0 x 5.00 x 140.0 mm

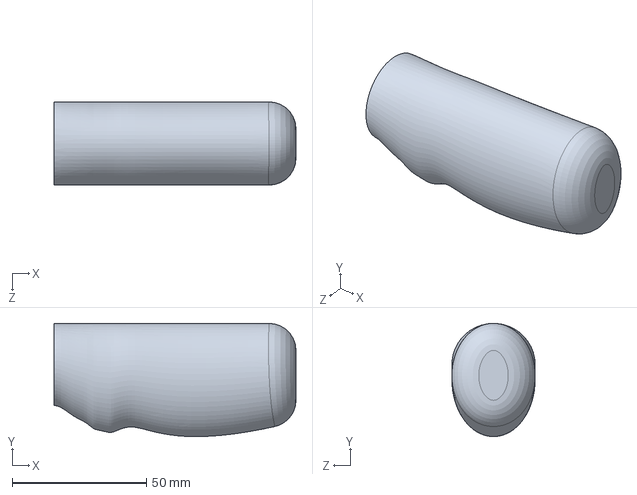
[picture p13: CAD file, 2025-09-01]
wildpose/hardware/Handle.SLDPRT
90.0 x 42.1 x 30.9 mm

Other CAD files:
wildpose/hardware/SKF_61807.SLDASM
wildpose/hardware/SKF_51200.SLDASM
wildpose/hardware/SKF_61801.SLDASM
wildpose/hardware/SKF_61807_45.SLDPRT
wildpose/hardware/SKF_51200_17.SLDPRT
wildpose/hardware/SKF_61801_16.SLDPRT
wildpose/hardware/18 T 2.032mm P , 6mm W Pulley.SLDPRT
wildpose/hardware/25d-metal-gearmotor-75-99-encoder.step.SLDPRT
wildpose/hardware/Base Encoder Holder (Printed).SLDPRT
wildpose/hardware/Belt Pulley 778-4828.SLDPRT
wildpose/hardware/Camera Mount.SLDPRT
wildpose/hardware/HandleRod.SLDPRT
wildpose/hardware/Lens Support.SLDPRT
wildpose/hardware/Lens.SLDPRT
wildpose/hardware/Motor Belt.SLDPRT
wildpose/hardware/Motor Mount.SLDPRT
wildpose/hardware/Nvidea Xavier.SLDPRT
wildpose/hardware/Pitch Encoder Holder (Printed).SLDPRT
wildpose/hardware/QLED Screen.SLDPRT
wildpose/hardware/RPi M3 Screw Connectors.SLDPRT
wildpose/hardware/SKF_51200_13.SLDPRT
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

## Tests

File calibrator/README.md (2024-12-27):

# Manual Calibrator for WildPose v1.1

This tool helps calibrate camera parameters for the WildPose system. It allows users to manually adjust both intrinsic and extrinsic camera parameters through an interactive interface.

## Purpose
- Assists in fine-tuning camera calibration parameters for WildPose
- Provides visual feedback for parameter adjustments
- Enables batch processing of multiple frames
- Supports manual refinement of auto-calibrated results

## Installation
```bash
$ conda env create -f environment.yml
$ conda activate wildpose
```

## Usage
1. Configure your settings in `debug_config.json`
2. Run the calibrator:
```bash
$ python manual_calibrator.py --config debug_config.json
```

## Controls and Operation
```yaml
# Intrinsic Parameter Controls
←/→: Adjust principal point (c_x) left/right
↑/↓: Adjust principal point (c_y) up/down

# Extrinsic Parameter Controls
w/s: Increase/decrease camera pitch
a/d: Increase/decrease camera yaw
e/q: Increase/decrease camera roll
W/S: Increase/decrease camera Z position (depth)
A/D: Increase/decrease camera X position

# Additional Controls
0: Reset all parameters to default
m: Merge frames in current batch
c: Toggle point color display mode
>/< : Increase/decrease adjustment step size
n: Advance to next frame
Enter: Save current parameters
```

## Output
The calibrator saves the adjusted parameters in the format specified in your configuration file. These parameters can then be used in the main WildPose system for accurate pose estimation.

## Acknowledgement
This project is based on [victoresque/pytorch-template](https://github.com/victoresque/pytorch-template).

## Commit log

2024-12-27 feat: add new scripts for trajectory validation and calibration analysis, update existing applications for improved data handling and visualization
2024-12-27 docs: add environment configuration and enhance README for WildPose calibration tool
    - Introduced `environment.yml` for easy setup of dependencies.
    - Updated README to clarify purpose, installation steps, usage instructions, and control mappings for the manual calibrator.
2025-07-11 feat: update README and restructure dji_rs3_pkg
    - Removed outdated sections from README.md related to hardware setup and configuration.
    - Added new instructions for using the Logitech Wireless Gamepad F710.
    - Introduced CMakeLists.txt for dji_rs3_pkg to manage build dependencies.
    - Deleted unnecessary scripts and files from dji_rs3_pkg to streamline the package.
    - Updated package.xml to reflect changes in dependencies and build type.
    - Added new gamepad_pkg for handling gamepad input, including setup files and test cases.
2025-09-01 feat: add the CAD model
    [18 T 2.032mm P , 6mm W Pulley.SLDPRT, 25d-metal-gearmotor-75-99-encoder.step.SLDPRT, 36 T 2.032mm P, 6mm W Pulley.SLDPRT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]
2025-10-02 feat: add loguru for enhanced logging in video_maker.py
    - Integrated loguru for logging instead of print statements to improve output management.
    - Updated pyproject.toml and uv.lock to include loguru as a dependency with version >=0.7.3.
2025-10-02 fix: correct memory handling in deserialize_livox_imu.cpp
    - Updated memory copy operations to correctly reference the frame_id_cstring.
    - Ensured proper string construction from the copied data to prevent potential issues with memory access.
2025-10-20 chore: add deserializer script for processing camera data with support for raw image generation and customizable output formats
2026-01-02 feat: implement variable frame rate (VFR) video generation from image sequences and refactor timestamp extraction
2026-06-17 build: add pixi environment for the calibrator
    Problem: the calibrator only shipped a conda environment.yml that was an
    osx-64 (Intel) dump of a shared research env, bloated with packages the
    tool never imports. It does not resolve natively on osx-arm64.
    Solution: migrate to pixi. Python comes from conda-forge; the actual
    runtime deps (numpy/scipy/torch/torchvision/open3d/opencv/matplotlib/
    pandas/seaborn/pillow/tqdm/tensorboard) are pinned on PyPI to the original
    versions, keeping a single ABI source. Force OMP_NUM_THREADS=1 via
    [activation.env] to stop the open3d+torch dual-libomp OpenMP deadlock on
    macOS. Document the design judgments in CLAUDE.md.
    Implications: target platform is osx-a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
2026-06-17 fix: import open3d before torch to avoid macOS OpenMP crash
    Problem: on macOS (Apple Silicon) open3d and torch each bundle their own
    libomp. Importing torch first aborts immediately with
    "OMP: Error #179 ... pthread_mutex_init failed".
    Solution: import open3d ahead of torch in the entry point.
    Implications: pairs with OMP_NUM_THREADS=1 in pixi.toml, which prevents
    the related dual-libomp deadlock in torch's threaded ops.
2026-06-17 chore: point debug_config at lion_walk and shrink batch_size
    Problem: the configured data_dir had no frames (empty dataset ->
    StopIteration), and batch_size=100 made startup preprocess up to 100
    frames synchronously before the window appears.
    Solution: set data_dir to data/lion_walk and reduce batch_size to 5.
    Implications: the visual debugger now starts in a few seconds; batch is
    only used for scrubbing frames, so a small size is enough.
2026-06-17 chore: stop tracking the calibrator/data symlink
    Problem: calibrator/data is a local symlink whose target is a
    machine-specific absolute path, so tracking it would break clones and
    other machines.
    Solution: untrack it (git rm --cached) and add /data to .gitignore so the
    symlink stays local-only.
    Implications: each machine points calibrator/data at its own dataset
    location; the path is no longer carried in git history.
2026-10-23 fix(deps): move to Python 3.11 for Pillow 13.0.0 (CVE-2026-112900)
    Problem: Pillow 13.0.0 is the only release that fixes CVE-2026-112900 (GHSA-w889-685w-c8fh, EPS file names passed to Ghostscript unsanitised), and it requires Python 3.11 or newer. The calibrator pixi environment and both environment.yml files were on Python 3.8 with Pillow 10.4.0. The environment.yml files were raw `conda env export` dumps with py38/osx-64 build strings, so changing the python line alone would not solve.
    Solution: calibrator/pixi.toml moves to python 3.11.* and pillow 13.0.0, and numpy goes from 1.23.1 (no cp311 wheels) to 1.23.5, the lowest version opencv-python 4.10 accepts on Python 3.11. It stays below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
2026-10-23 fix(deps): bump packages with High/Critical advisories
    Problem: after the move to Python 3.11, OSV still reported 5 Critical and 34 High advisories for the package set that environment.yml installs. Among them, certifi 2024.7.4 still trusts the compromised eMudhra roots (GHSA-6q48-6c7w-9gw2), and h11, anyio, pyjwt, urllib3, aiohttp, cryptography and protobuf were also affected. The pinned conda C libraries (openssl 3.4.0, sqlite 3.45.3, zlib 1.2.13, xz 5.6.3, c-ares 1.34.4, and CPython 3.11.9 as resolved) have High/Critical CVEs, and calibrator/pixi.lock carried vulnerable cryptography, fsspec, pyasn1, setuptools, urllib3, wheel and openssl.
    Solution: in both environment.yml files, every pa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
